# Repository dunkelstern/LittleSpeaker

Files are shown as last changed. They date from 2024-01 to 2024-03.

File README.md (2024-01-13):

---
title: LittleSpeaker
author: Johannes Schriewer
date: January 2024
toc: true
lof: true
numbersections: true
geometry: margin=2.5cm
urlcolor: blue
papersize: a4
header-includes: |
    \usepackage{fancyhdr}
    \pagestyle{fancy}
    \lfoot{13.01.2024}
    \rfoot{Page \thepage}
include-before:
- '`\newpage{}`{=latex}'
fontfamily: universalis
---

# LittleSpeaker

This is the Git-Repository for the LittleSpeaker Project. The idea is to build
a small mono speaker that is repairable, hackable and can do some more advanced things
than just being a Bluetooth speaker.

Design of the enclosure is by Jennifer Leis, Firmware and electronics by me.

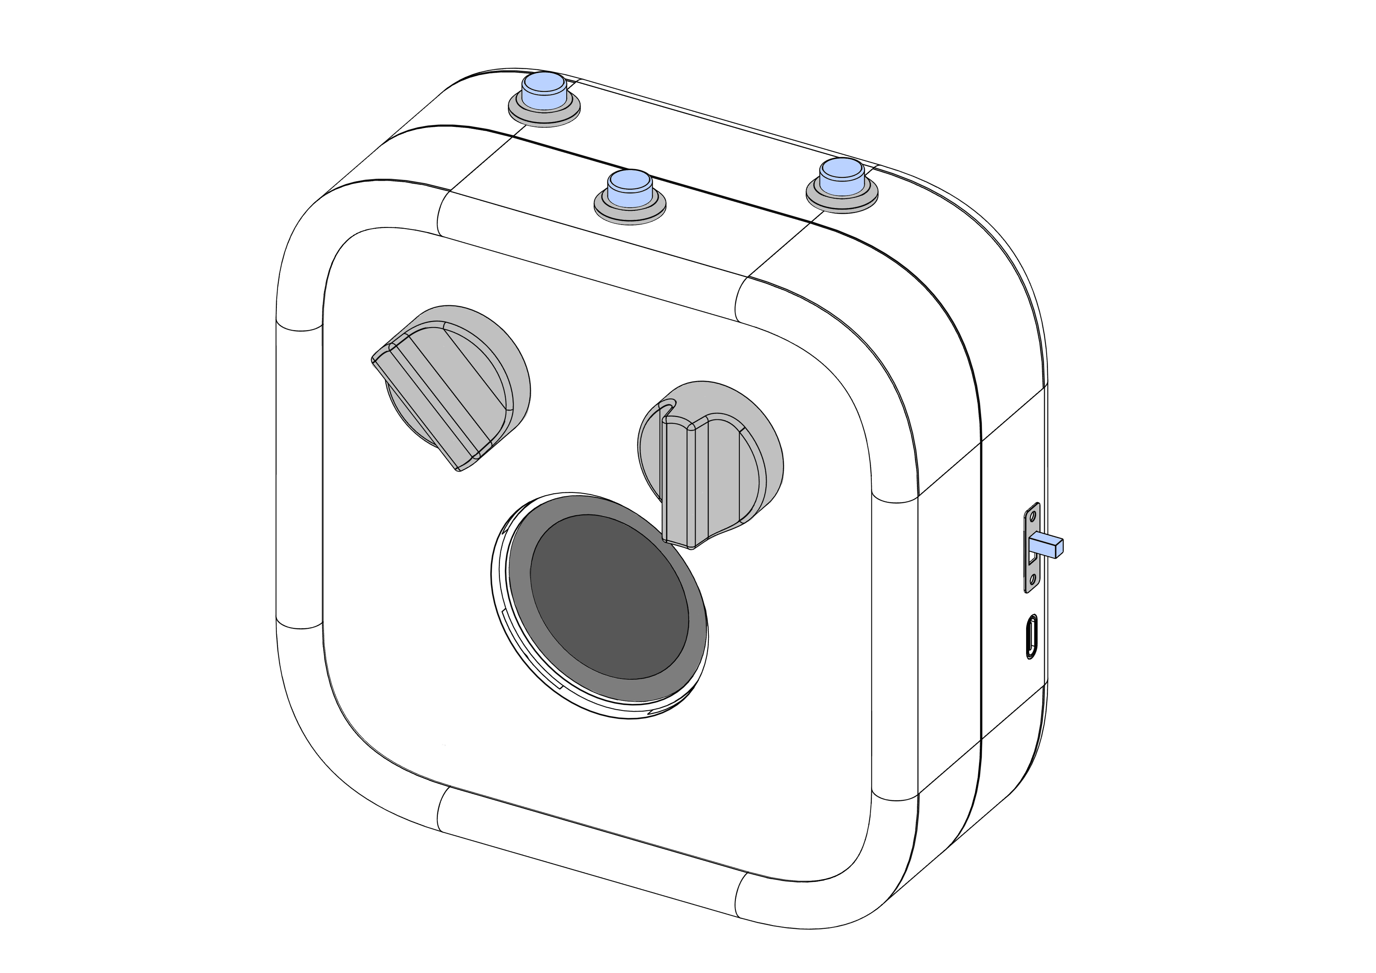
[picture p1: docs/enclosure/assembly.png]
Assembly graphic


\newpage{}

## Enclosure

The prototype enclosure was 3D printed and is held together by a hinge and just one
M3 screw.

You will need:

1. 1x [Front bezel](enclosure/front-bezel.step)<div>
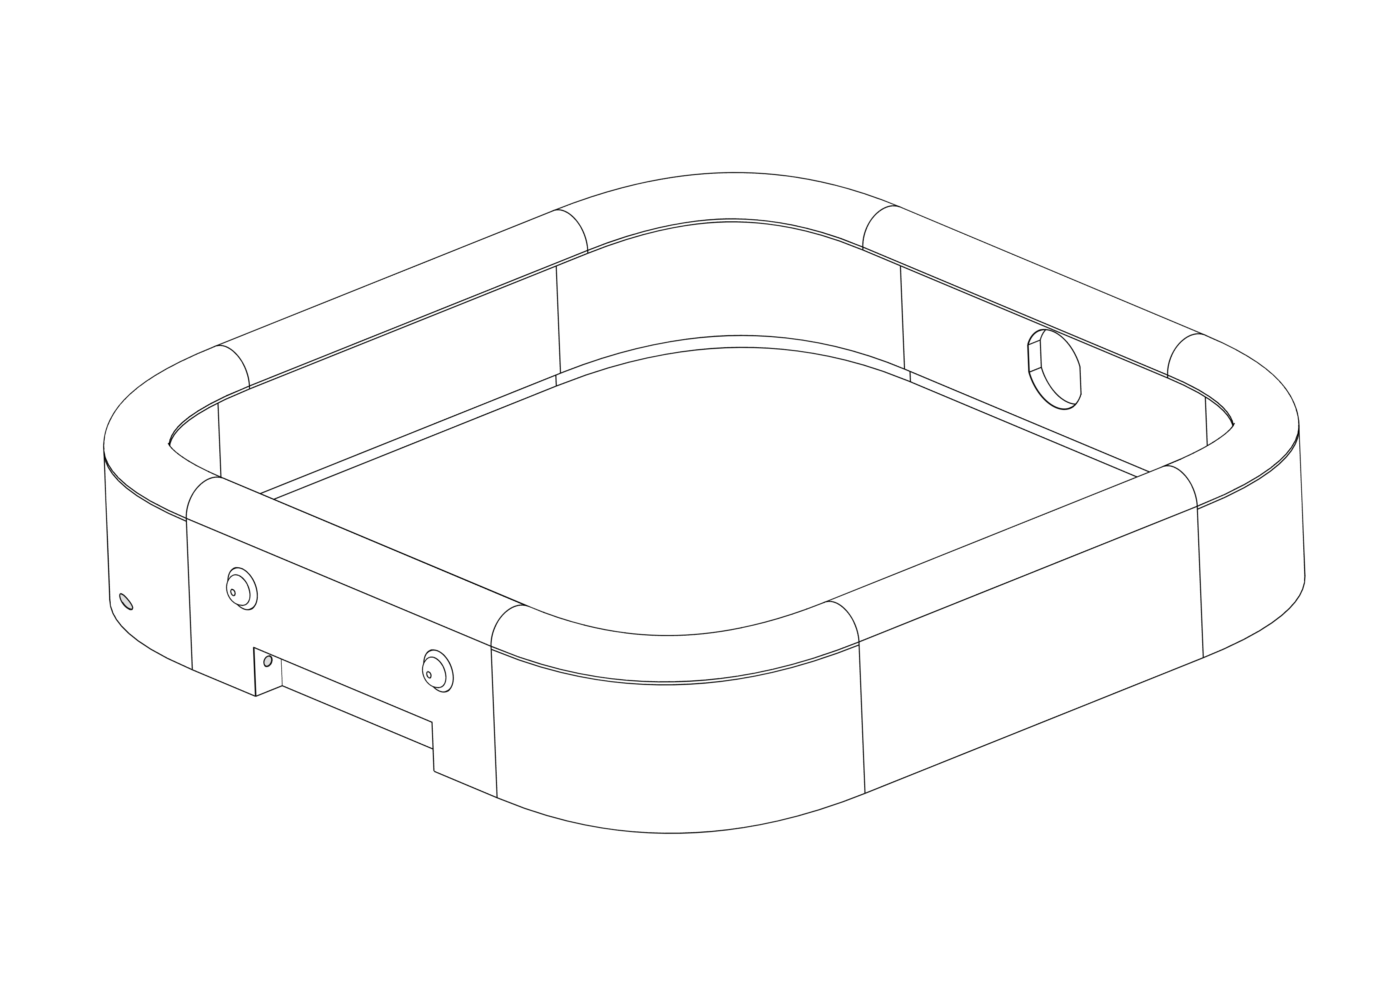
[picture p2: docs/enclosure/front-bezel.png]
Front bezel graphic
   </div>
2. 1x [Back bezel](enclosure/back-bezel.step)<div>
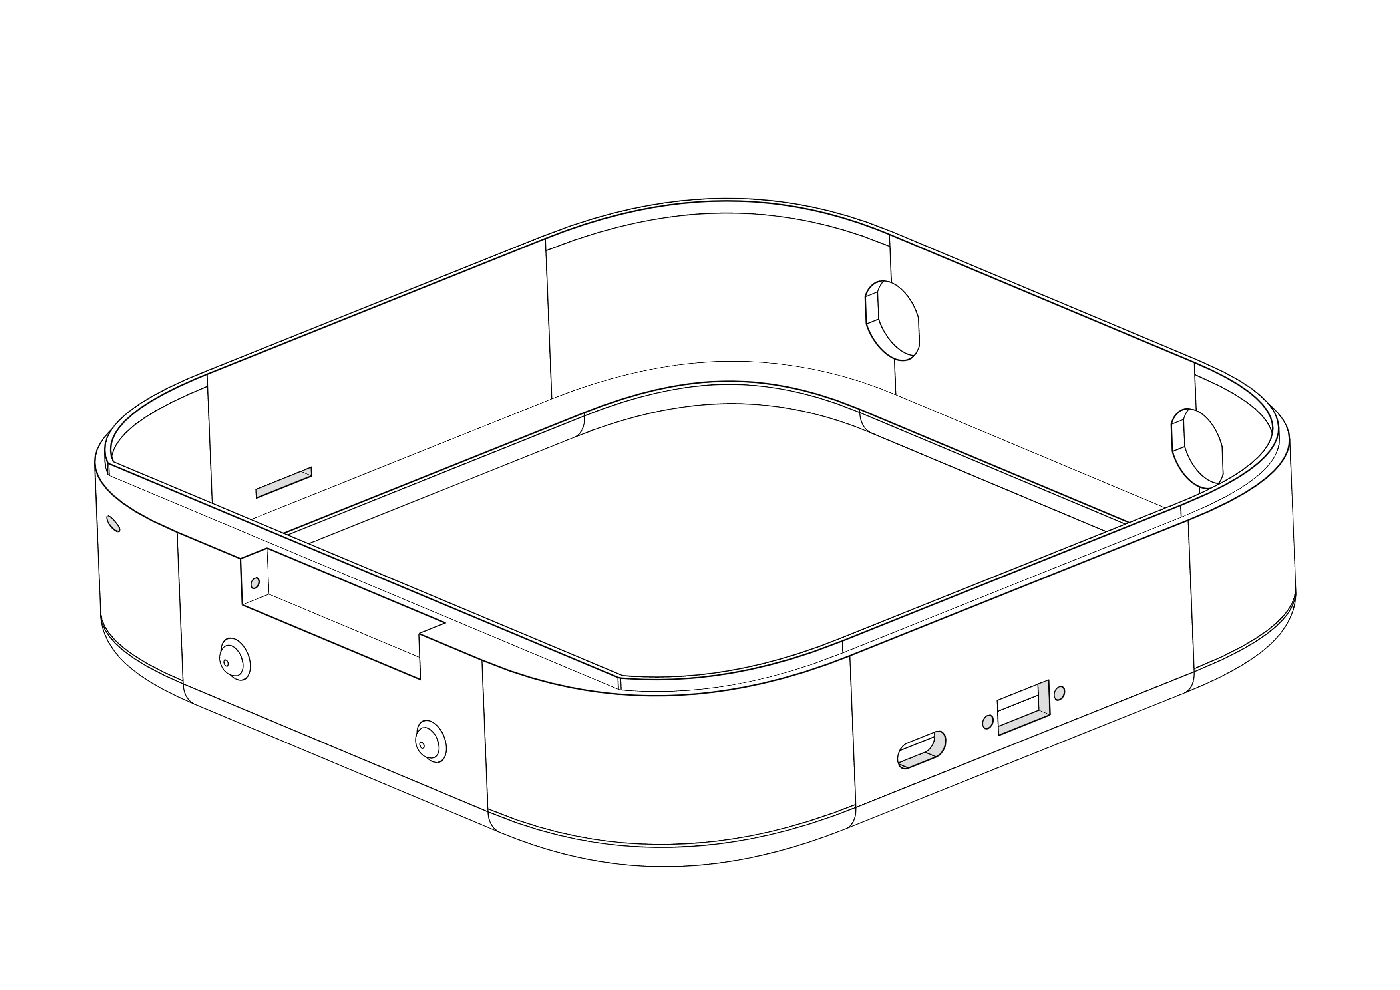
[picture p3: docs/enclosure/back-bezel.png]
Back bezel graphic
   </div>
3. 1x [Back plate](enclosure/back-plate.step)<div>
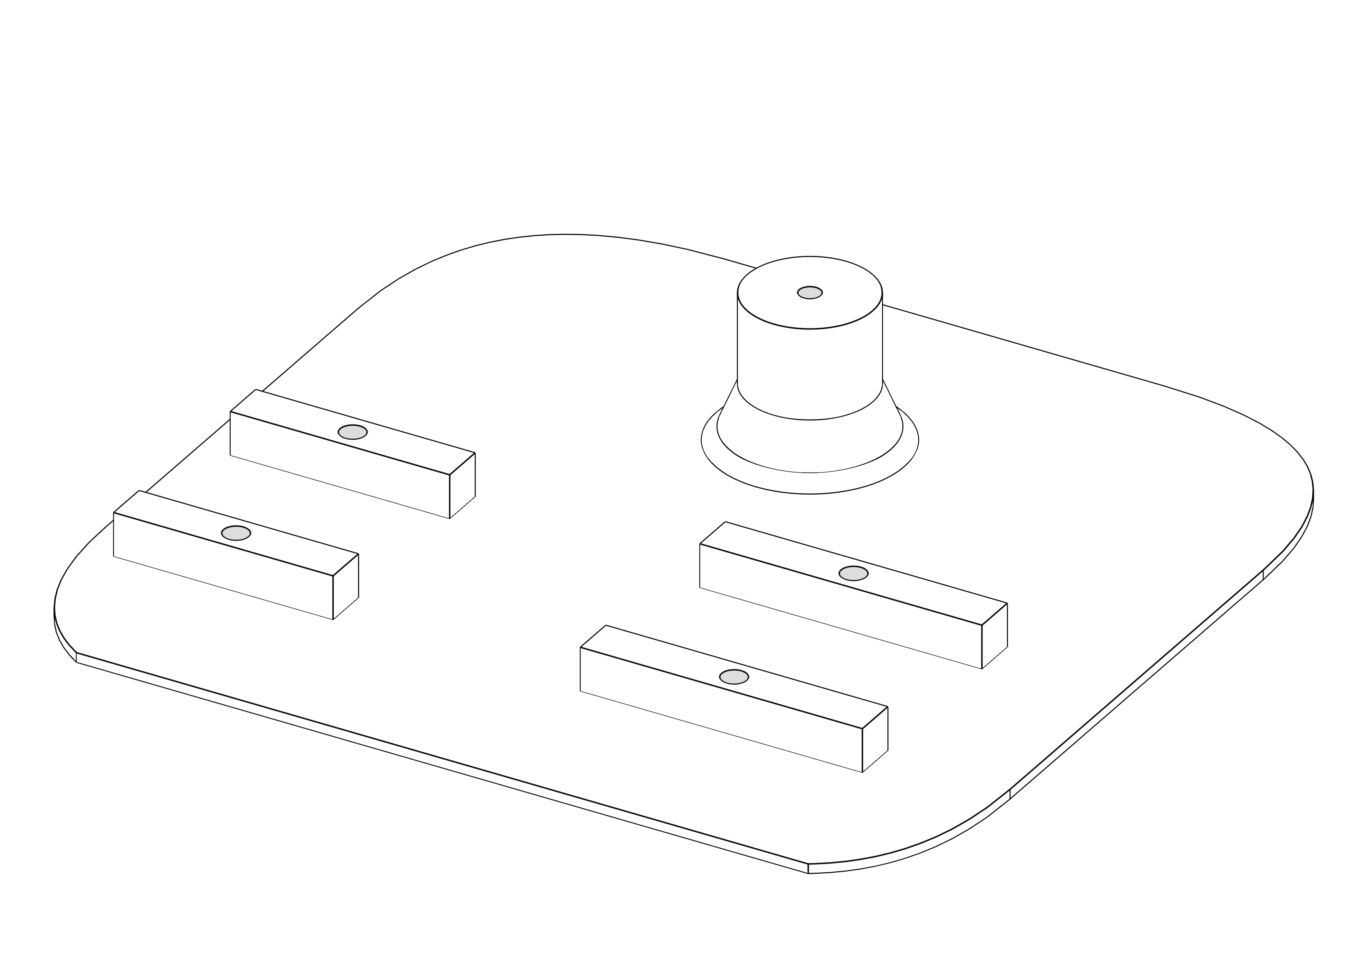
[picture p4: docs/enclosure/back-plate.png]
Back plate graphic
   </div>
4. 1x [Front plate](enclosure/front-plate.step)<div>
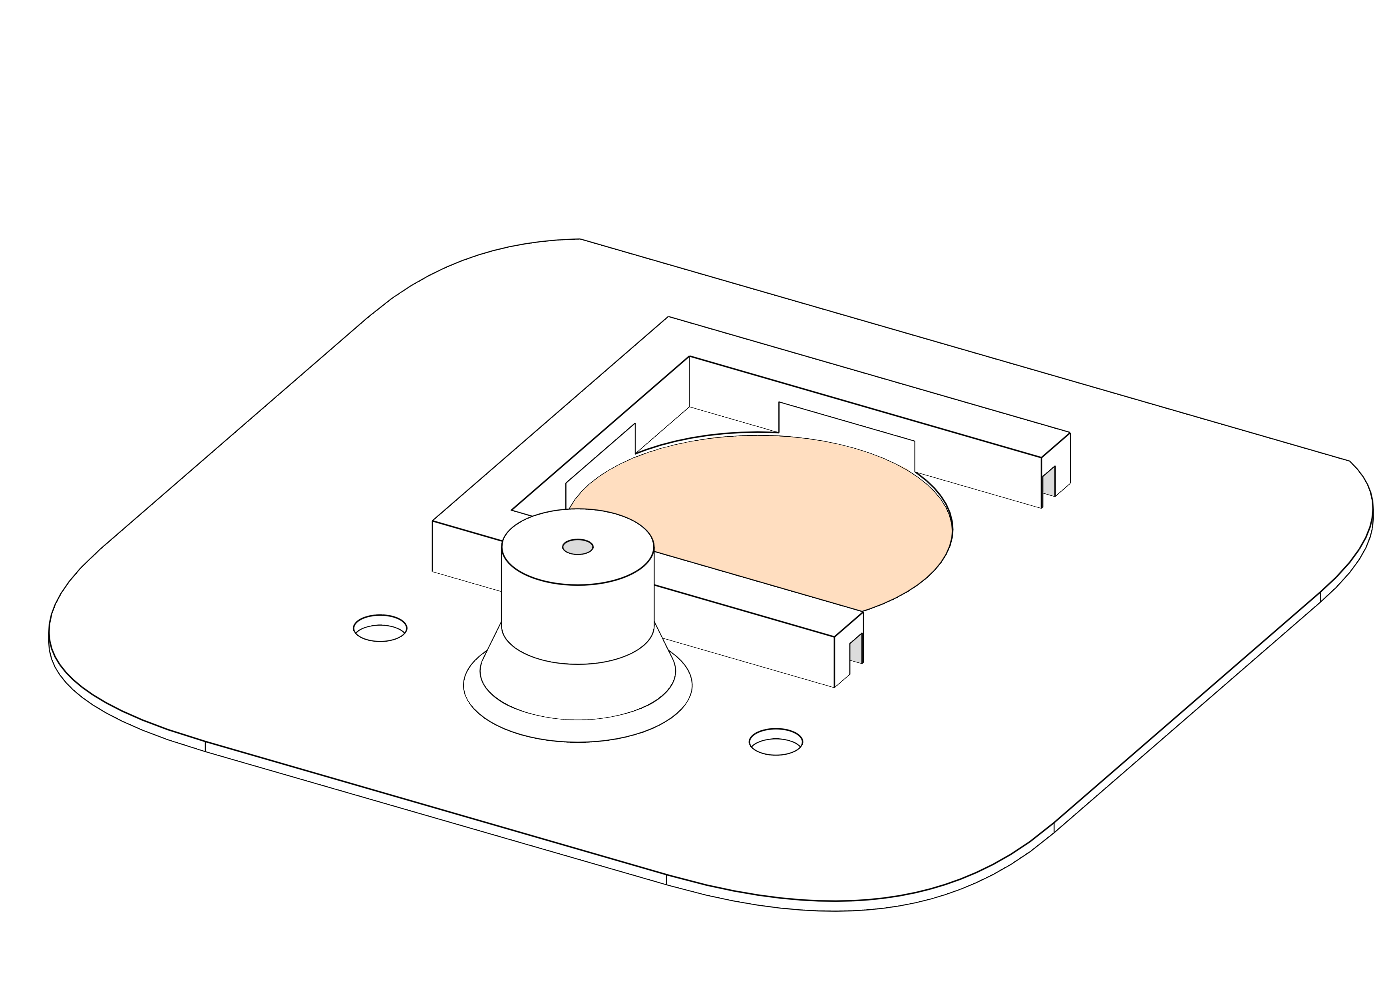
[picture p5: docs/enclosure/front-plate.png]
Front plate graphic
   </div>
5. 1x [Hinge](enclosure/hinge.step)<div>
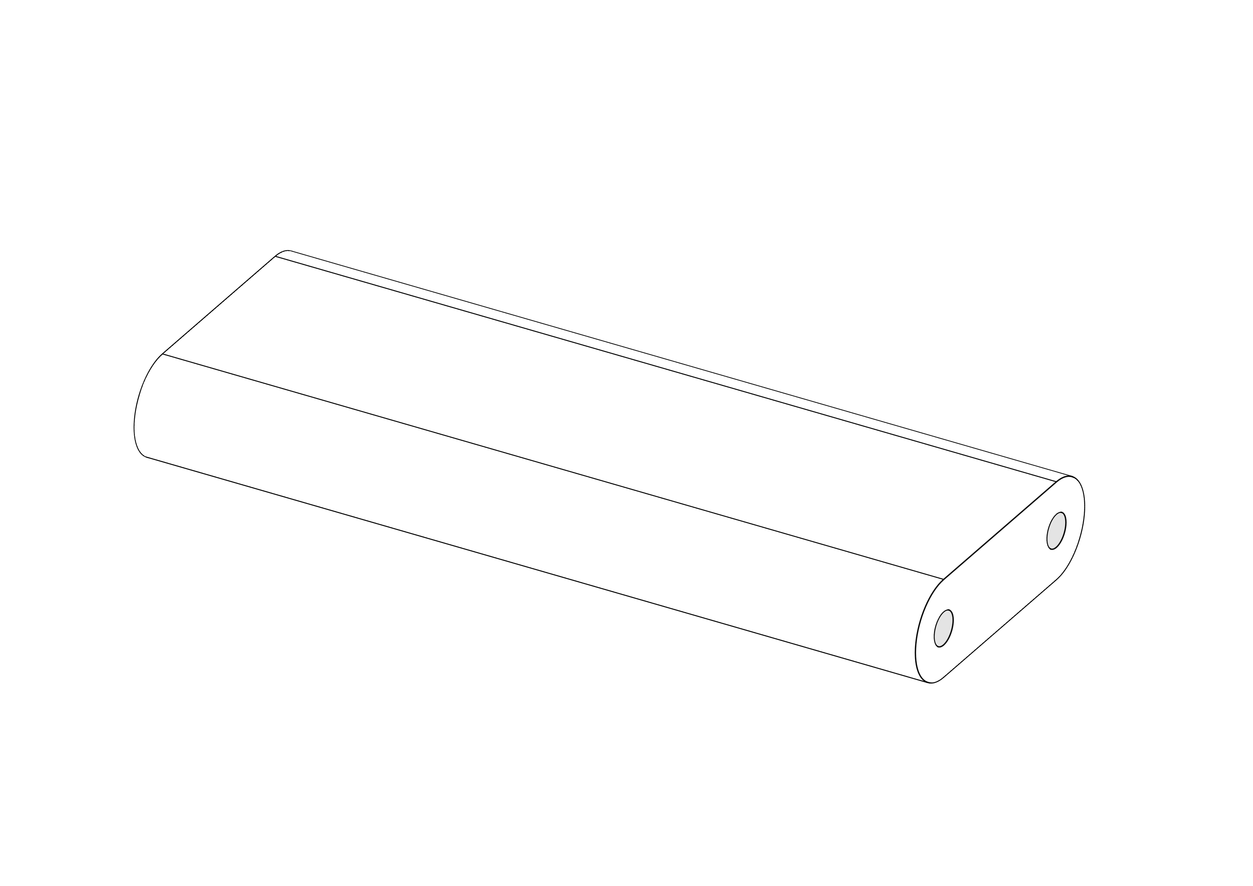
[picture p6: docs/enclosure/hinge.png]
Hinge graphic
   </div>
6. 2x [Knob](enclosure/knob.step)<div>
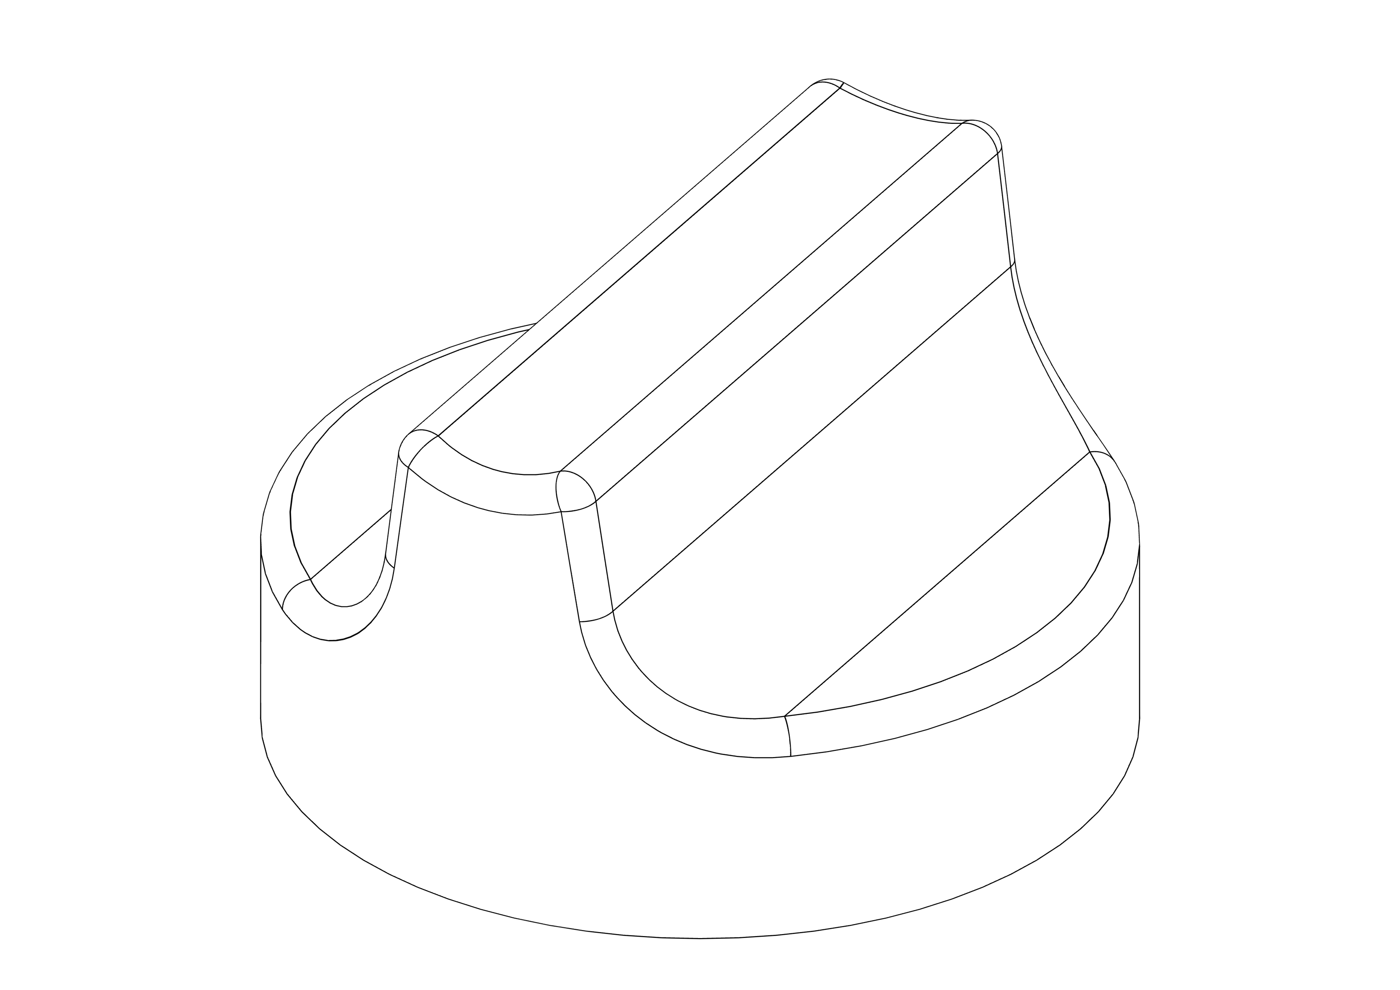
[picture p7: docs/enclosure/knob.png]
Knob graphic
   </div>
7. Two small pieces of wood or plastic as holding braces for the PCBs
   that will be accessible from the outside (15 x 40mm two M3 trough holes)<div>
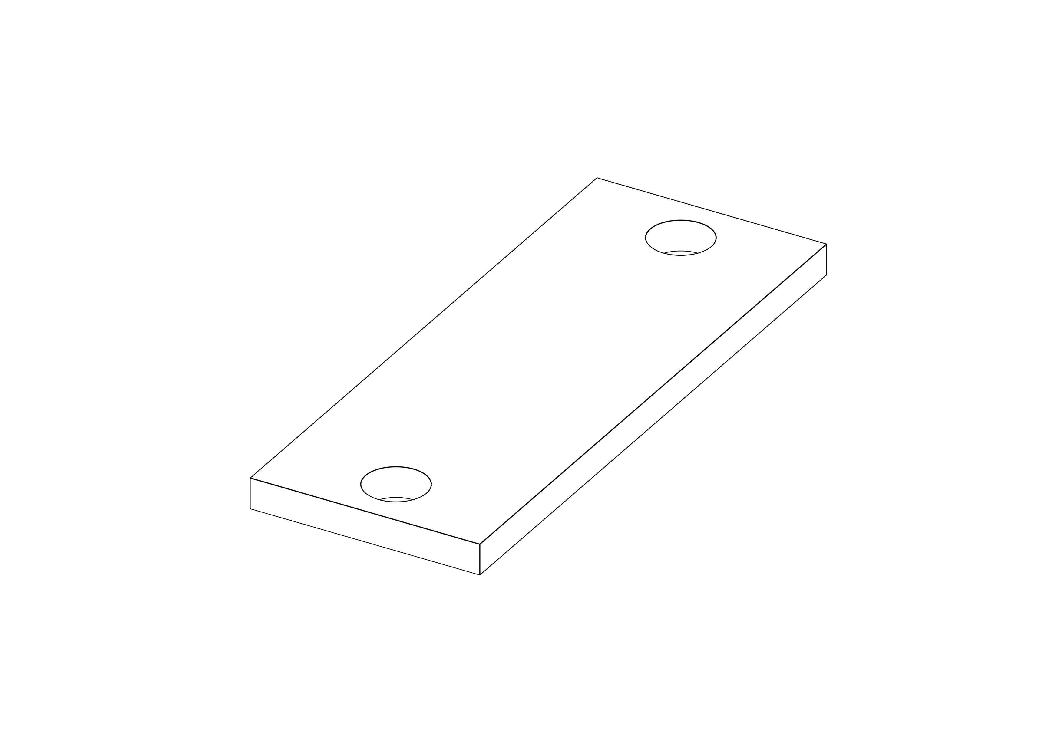
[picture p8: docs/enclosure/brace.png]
Braces graphic
   </div>
8. Brass hotmelt inserts for screwing the front and back together and for the braces:
   - 1 x M3x6
   - 4 x M3x4
   <div>
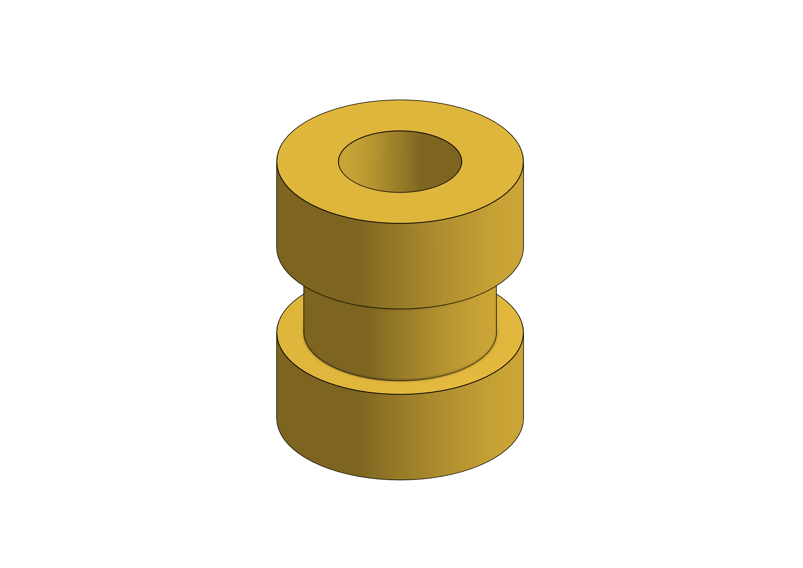
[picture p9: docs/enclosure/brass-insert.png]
Brass insert graphic
   </div>
9. 5x M3x10 Cap head screws
10. Some self-tapping screws to attach the power switch.
11. A piece of Copper wire to fit into the hinge to connect the front and back pieces
12. Glue to glue the front and back plates into the bezels and some foam rubber strips
    or foam tape for securing stuff
13. Some wool or cotton to fill the empty spaces so no wires rattle around.

When printing the front plate make sure to change the settings for the speaker grille
part to not print any bottom or top layers, use hexagon/honeycomb infill and use about 
40% infill strength. You can remove the speaker grille part if you want to have the
speaker open like you can see in the rendered graphic of the assembly.

\newpage{}

### After printing:

1. Remove the supports from the holding brackets of the speaker driver.
   There should be thin walled supports that have been designed into the part.
2. Melt the inserts into the brace holes and the front plate.
3. Glue the front and backplates into their bezels
4. Find a piece of copper wire that fits into the holes in the hinge.
   The front and back bezels both have a small hole through which you can insert
   the wire through the hinge part. If assembled and the hinge is freely rotating
   you can use a small screw driver to bend the wire in the hole to avoid it falling out.
   Alternatively insert a dab of glue to close the hole.
5. The SD card slot and USB-C port probably need some cleanup and filing to fit perfectly.

\newpage{}

## Electronics

The electronics in this devices are meant to be modular, so developer boards for all
components were used and the wiring connections mostly have dupont connectors to be able
to remove/replace a component without de-soldering anything. You can of course skip the
connectors and solder everything together, that's your choice.

### BOM

- DFRobot Firebeetle 2 ESP32-E (ESP32 development board with battery charger and USB-C)<div>
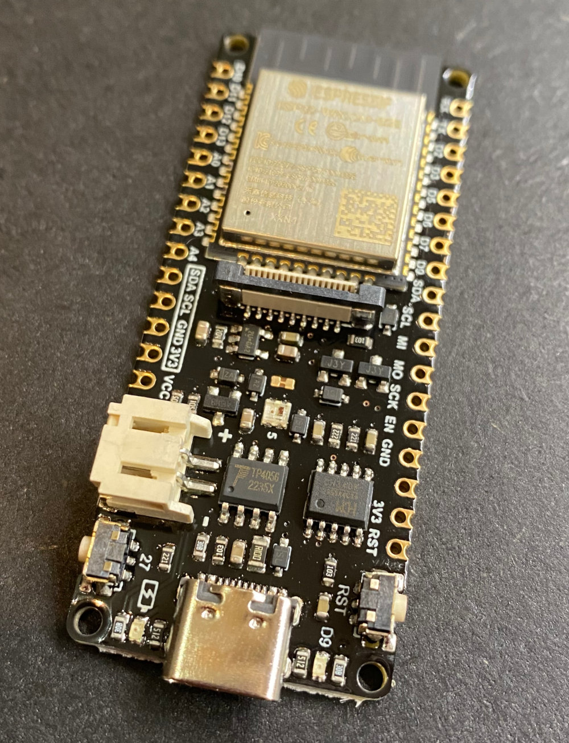
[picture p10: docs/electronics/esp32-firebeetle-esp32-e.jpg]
Firebeetle ESP32-E
  </div>
- I2S DAC usually something like a `PCM5102A`<div>
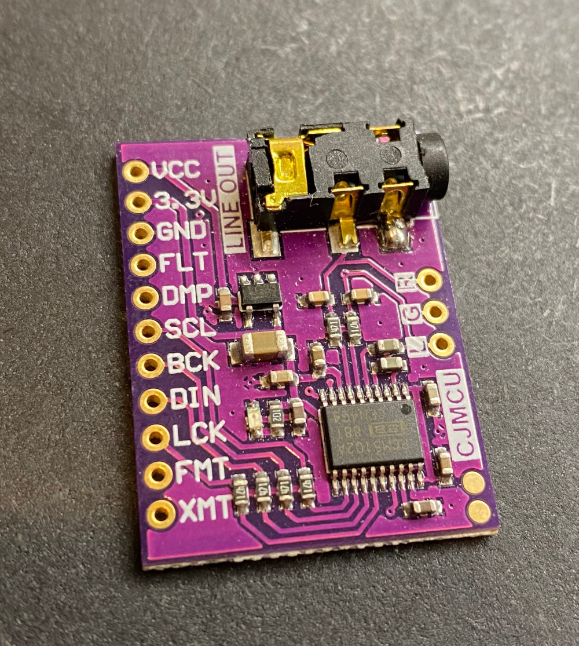
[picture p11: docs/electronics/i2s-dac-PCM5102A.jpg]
I2S DAC
  </div>
- Micro SD Card reader, see below for more instructions!<div>
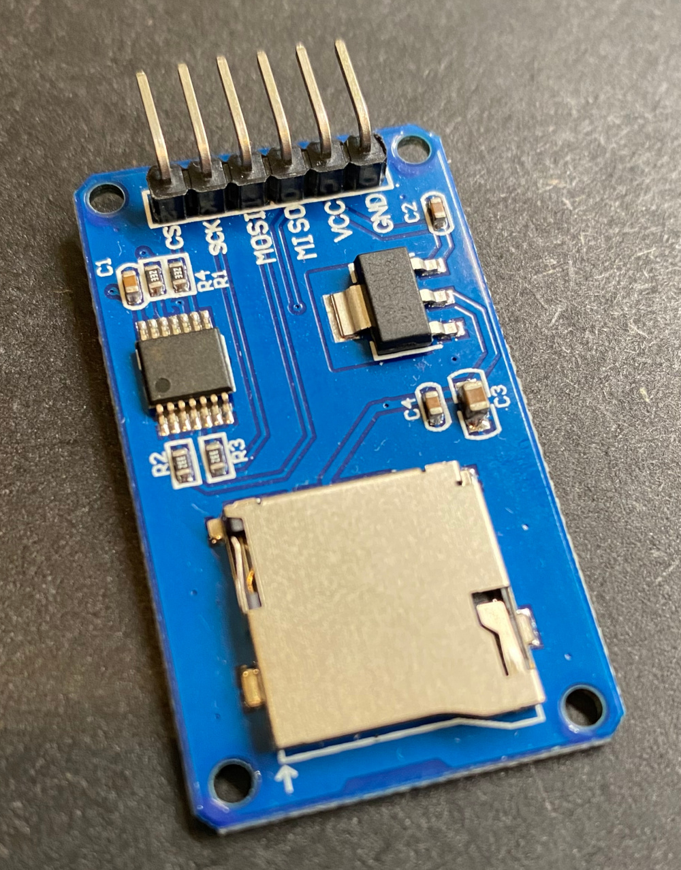
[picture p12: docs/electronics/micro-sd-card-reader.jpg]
SD-Card Reader
  </div>
- Class D Amplifier for 1.5W to 4W with volume regulation, for example `PAM8403`<div>
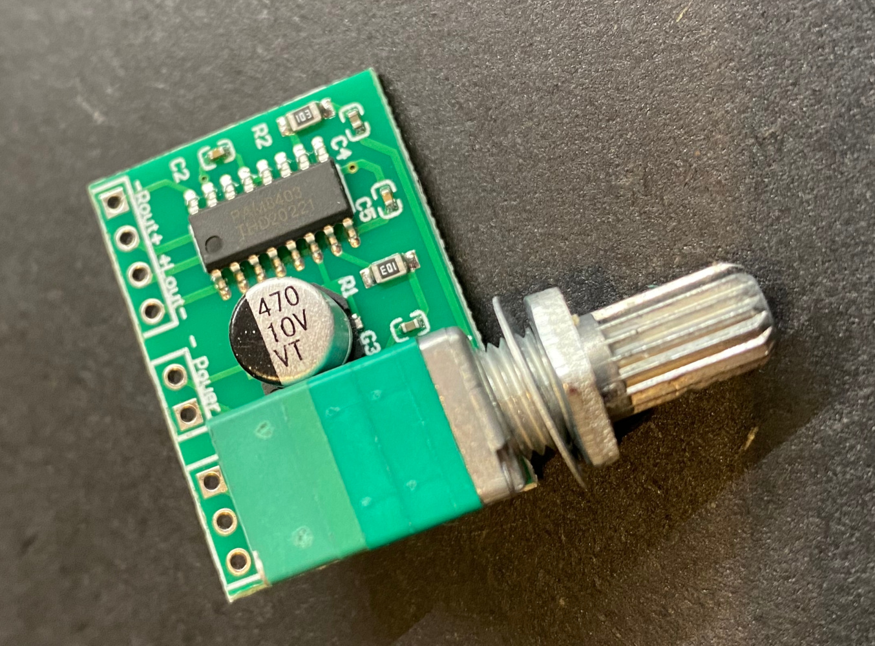
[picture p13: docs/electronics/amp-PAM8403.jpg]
Class D amp
  </div>
- "57mm Speaker" (yes this is the search term). You can probably use any speaker you
  want as long as it is 4-8 Ohms and can work with your amplifier.<div>
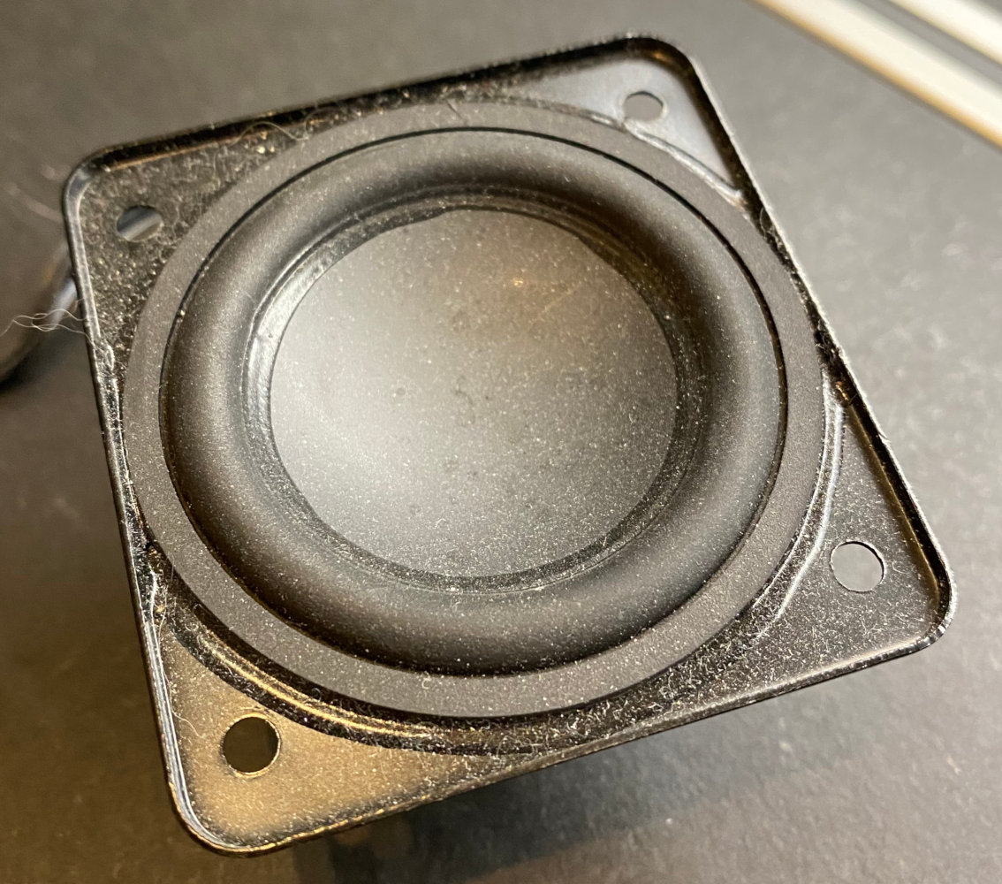
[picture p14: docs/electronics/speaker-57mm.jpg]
Speaker
  </div>
- LiIon 18650 Battery<div>
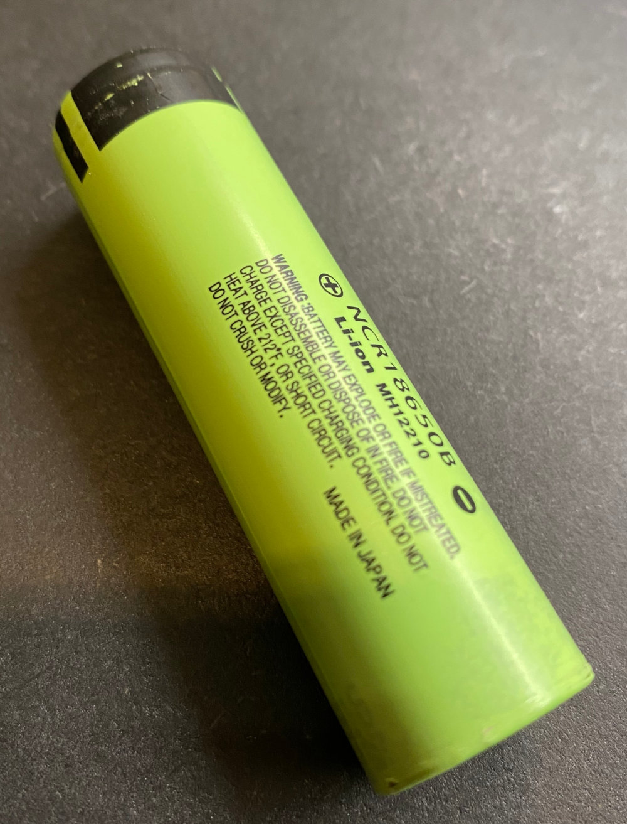
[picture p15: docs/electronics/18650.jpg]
  </div>
- Battery holder<div>
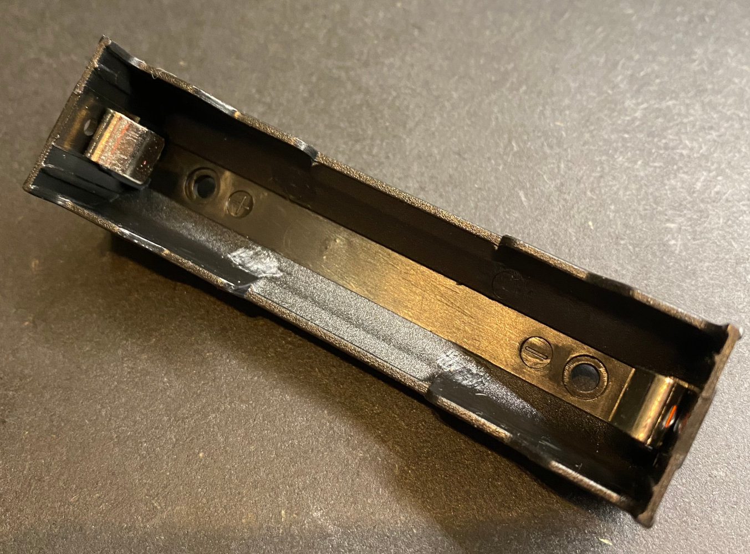
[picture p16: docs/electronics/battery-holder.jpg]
Battery holder
  </div>
- 3x Round pushbutton. If you cannot find these, you probably can use others if you
  have some patience and a file for the holes ;)<div>
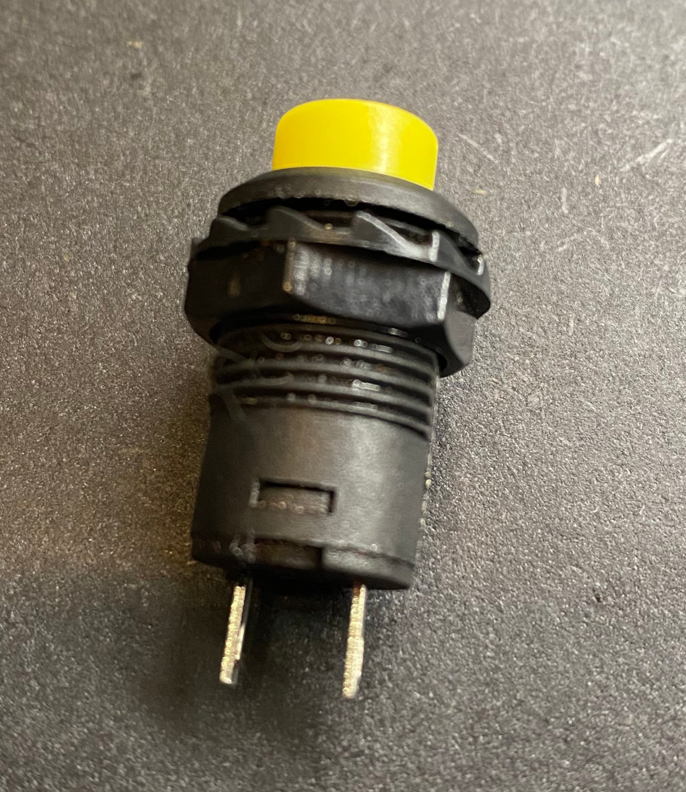
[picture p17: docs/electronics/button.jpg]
Buttons
  </div>
- Sliding switch for power<div>
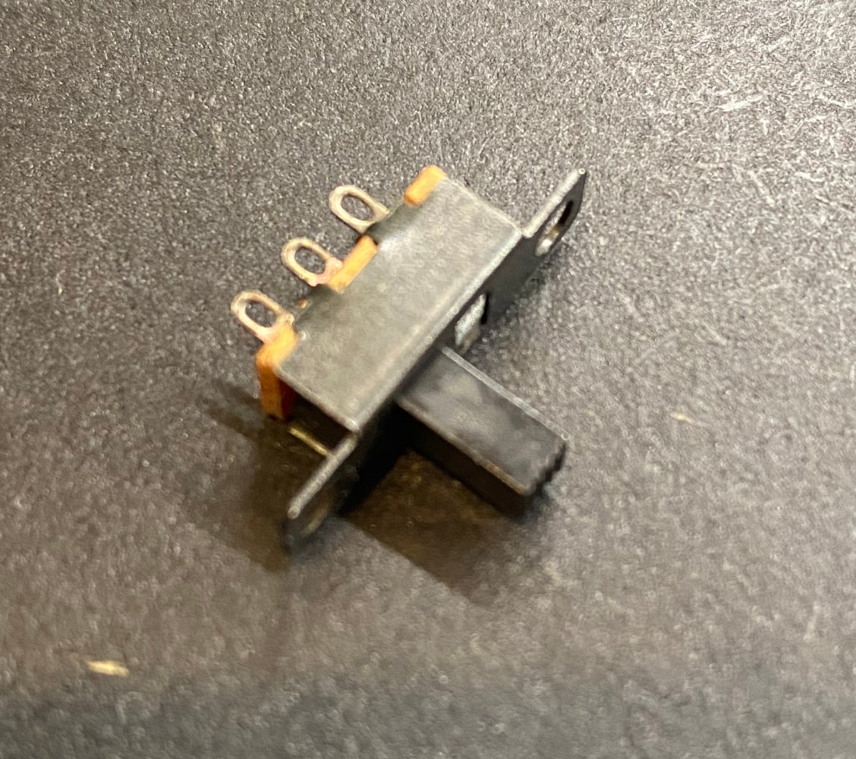
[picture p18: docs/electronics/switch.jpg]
Switch
  </div>
- Encoder with pullups, you can get modules that have pullups integrated, if you
  have no pullups integrated you can integrate resistors in your wiring.
  *Attention: this is not a potientometer but a gray encoder!*<div>
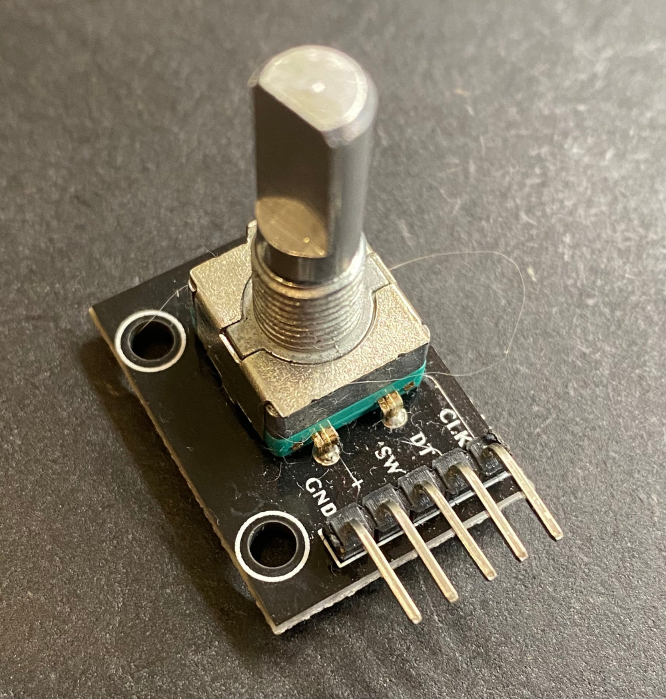
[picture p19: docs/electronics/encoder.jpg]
Encoder
  </div>
- 3 x 1kOhm resistor as pull up for the buttons
- Some multi colored wires, a soldering Iron and patience

\newpage{}

**SD-Card reader:**

Get a reader that has the Card slot as close to the edge as possible, if it is not at the
edge you can usually file away some of the FR4 board to make it fit. (Usually there are no traces there to destroy...).

<div>
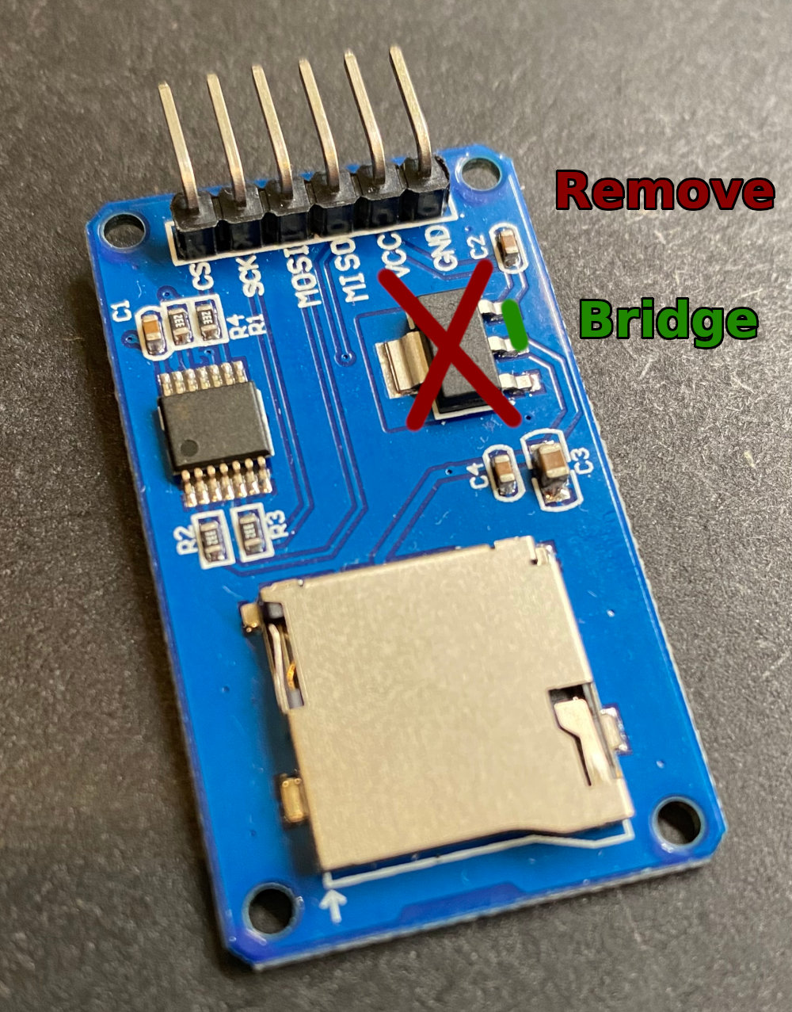
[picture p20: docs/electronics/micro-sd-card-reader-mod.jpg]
SD-Card reader Mod

</div>

Most SD-Card readers you can get on the market are designed to be used with 5V electronics
and contain a linear regulator (red X) to step down that voltage to 3.3V. As the ESP32
works on 3.3V already you'll have to remove that LDO because the minimal voltage it needs
to run is usually 4.5V. When removing the part either use hot air or just a soldering
iron and cook  that thing, as we won't be needing it you do not have to save it. After
removal just bridge input and output of the part (marked in green).

\newpage{}

### Wiring

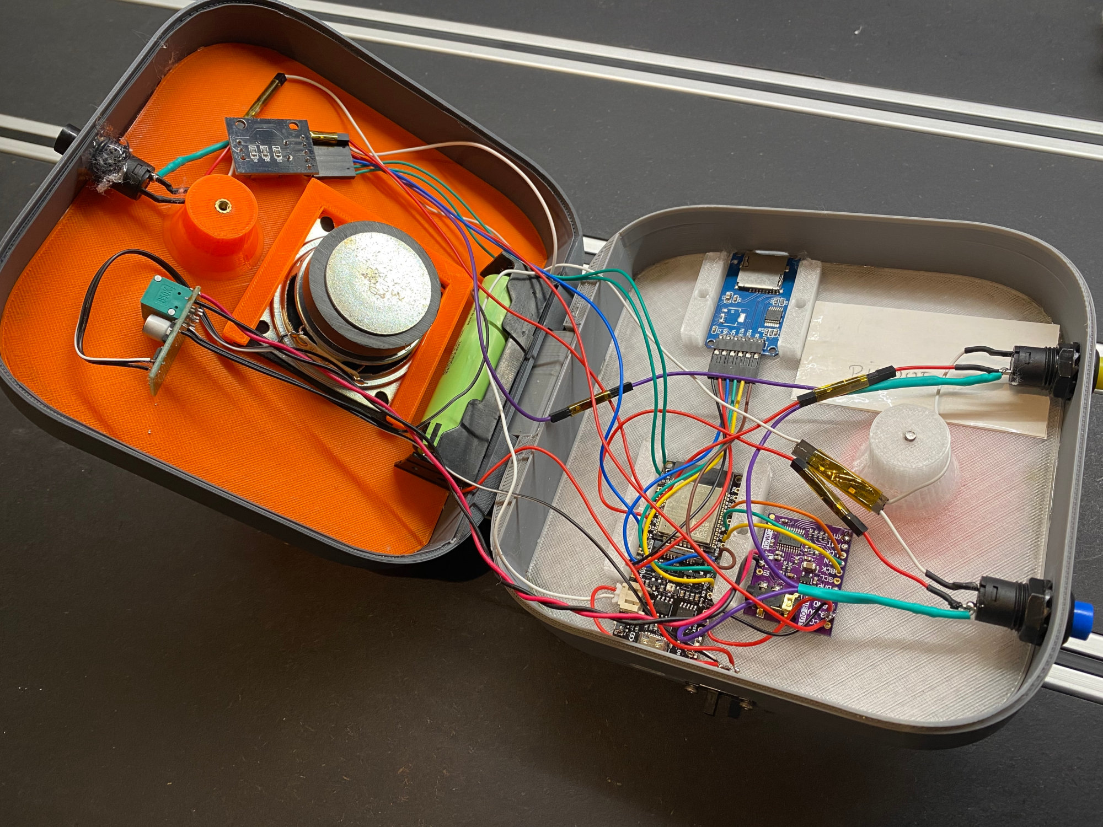
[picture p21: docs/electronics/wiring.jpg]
Wired up


Open the [Schematic](electronics/schematic/outputs/schematic.pdf) from `electronics/schematic/outputs/schematic.pdf`

<div>
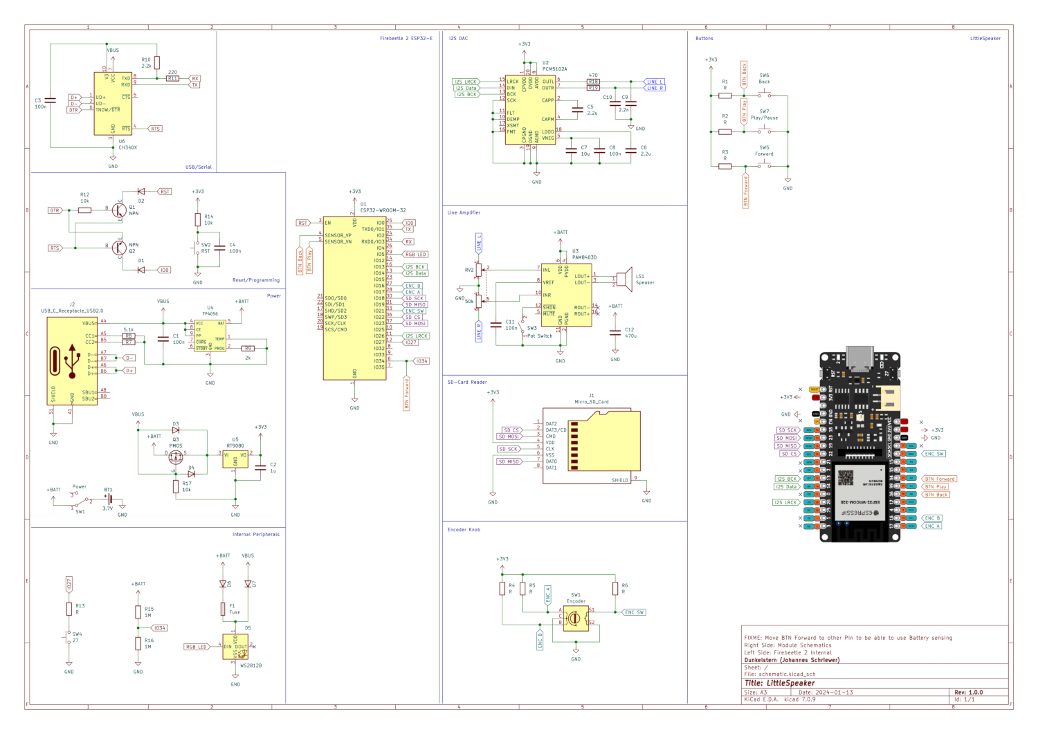
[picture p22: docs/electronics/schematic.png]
Schematic preview

</div>

Make sure to connect the Amplifier directly to the battery and **not** the ESP32. You will crash the ESP with loud music as the regulator on the PCB will not deliver enough power!

For the button pullup resistors I soldered them in-line with a wire and applied heatshrink over them (greenish heatshrink in the photo).

The development boards are glued with double sided tape and if needed you can apply the braces on top and stuff them with some foam tape or something rubbery to hold the boards down firmly.

The Speaker will slide into the printed rails but it will rattle around, you need some
foam tape or foam rubber strips to wedge the speaker into.

\newpage{}

## Firmware

The firmware is in this repository and is to be built with platform.io

The Arduino framework is used and these external libraries:

- ESP8266Audio 1.9.7 (Audio components)
- RotaryEncoder 1.5.3 (Encoder knob)
- AceButton 1.10.1 (Buttons)
- FixedPoints 1.1.2 (3 Band Equalizer)

Just open this repository in a Platform.io IDE of your choice and click "Build and Upload"

### Stuff you may want to change

**SD-Card read speed**

If you get errors on the serial debug console output about the SD-Card not working, you may have a slow SD-Card, go to `src/main.cpp` around line 35 and change the following line:

```cpp
#define SPI_SPEED 4000000u
```

40 MHz is the default and the maximum speed the ESP32 can handle. Try reducing to 20MHz
or 15 MHz until the SD-Card works. If you go too slow sound will be crackling and boot
times will increase.

**Equalizer settings**

As the EQ settings depend on the materials you printed the enclosure, print settings and
the used speaker driver you probably want to play with those settings a bit. You can find
them in `src/main.cpp` at around line 150.

Search for these lines:

```cpp
  eq = new AudioOutputFilter3BandEQ(output, 500, 5000);
  eq->setBandGains(1.5, 0.9, 1.3);
```

The first line sets the cutoff frequency of the EQ bands, so in this example we have 3
Bands:

- 0-500 Hz
- 500-5000 Hz
- 5000-22050 Hz

Those values are approximate as the algorithm implemented for the EQ is very simple and
not accurate at all, but as we're dealing with very simple and cheap components here it is
usually ok to use that.

The second line sets the equalizer band gains. If you set them all to *1.0* you should 
hear the original sound. I recommend to use values in the range of *0.75* to *1.5*. If you
go under or over those the sound may distort or clip, I warned you!

## SD-Card

To properly function the speaker needs an SD-Card to store voice prompts and 
configuration. I personally tried with 16GB SD-Cards and it worked fine (those were the
smallest cards i could get from my supplier), I think that is enough space for this project as two full days of music are just under 4GB and if you put too many directories
on there the boot time of the device will take ages as it needs to build an index of the
contents on boot up.

To prepare the SD-Card for the speaker:

1. Format the SD-Card to FAT32
2. Put all files from the `sd-card` folder directly onto the SD-Card
3. Read the [Readme](sd-card/README.md) of the SD-Card for more information

\newpage{}

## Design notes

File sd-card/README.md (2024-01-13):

# SD-Card contents

This is a quick how-to for the SD-Card contents of LittleSpeaker

## root files

We have some files that reside on the root directory (Top level, under
windows this is directly on the drive in no folder).

- `wifi.txt` WiFi settings, this file contains 2 lines:
   1. WiFi name, attention this is case sensitive
   2. WiFi password in plaintext
- `webradio.txt` URLs to webradio streams, start a line with `#` to
  include comments. See *webradio* below for more info

If the connection to the WiFi does not work check the following:

1. WiFi has to be on the 2.4GHz band, 5GHz does not work
2. WiFi has to support WPA2
3. If nothing else is the problem, check that you're using "Unix line endings",
   this is usually only a problem on Windows machines.

## System directory

The `system` directory should contain the announcer voice files to be used for
the menu system, I will describe which one is which in the following.

The default announcer voice has been generated with a text to speech computer
voice, but if you want you can exchange them for another voice.

Format of the files should be a *stereo* MP3 file with a reasonable bitrate and
length usable for the task. Remove all ID3 tag data to make the menu more
responsive.

- Numbers 1 to 99 (e.g. `1.mp3`): Will be used for
  - Album numbers if there is no announcer (see below at *album directories*)
  - Track numbers in albums
  - Webradio station numbers
- `album.mp3` used before an album number
- `bluetooth_on.mp3` used when entering the bluetooth menu and turning bluetooth on
- `bluetooth_pair.mp3` played when a device pairs to LittleSpeaker in bluetooth mode
- `bluetooth.mp3` menu title for the bluetooth menu
- `connection_failed.mp3` played when a connection to a webradio station fails or is
  disconnected by the server.
- `hello.mp3` will be played on bootup after SD-Card index has been created
- `sd.mp3` menu title of the SD-Card menu
- `stopped.mp3` played when an album has finished, the user disconnects a webradio
  station by pressing stop or when a device disconnects from bluetooth
- `track.mp3` played when in an album before the track number
- `webradio.mp3` menu title of webradio menu

## webradio

### Requirements

There are some things you'll have to consider for the streams that can
be played by the firmware of LittleSpeaker:

1. The stream has to be an IceCast or ShoutCast stream.
2. You have to link to a stream, not the stream's playlist. Usually webradio
   stations will link a playlist file (either `m3u`, `m3u8` or `pls`) which
   contains multiple streaming URLs to provide multiple servers.
3. The stream has to be MP3, AAC and HeAAC (or AAC+) do not work currently.
4. Keep the bitrate at a reasonable value, 320 kBit is cool and all, but you
   will probably not hear a difference to a 192 kBit (or even a 128 kBit) stream.
5. Try to keep to http and not https as it is faster to process on device
6. Maximum line/URL length is 255 characters
7. Maximum number of stations is 25

### Announcer

If you want LittleSpeaker to tell you a webradio name instead of the channel
number in the menu you can add an audio file to the `webradio` directory. The
file should be a *stereo* MP3 file with a reasonable bitrate and length.
Name it the channel number in two digits (leading zero). The file will be played
back if you select the channel.

### Verification

To verify a Stream URL fetch it with curl like this:
```
curl -v http://ice2.somafm.com/groovesalad-128-mp3
```

   You will get an output like this:
```
*   Trying 173.239.76.149:80...
* Connected to ice2.somafm.com (173.239.76.149) port 80
> GET /groovesalad-128-mp3 HTTP/1.1
> Host: ice2.somafm.com
> User-Agent: curl/8.4.0
> Accept: */*
> 
< HTTP/1.1 200 OK
< Content-Type: audio/mpeg
< Date: Fri, 12 Jan 2024 18:42:54 GMT
< icy-br:128
< icy-genre:Ambient Chill
< icy-name:Groove Salad: a nicely chilled plate of ambient beats and grooves. [SomaFM]
< icy-notice1:<BR>This stream requires <a href="http://www.winamp.com/">Winamp</a><BR>
< icy-notice2:SHOUTcast Distributed Network Audio Server/Linux v1.9.5<BR>
< icy-pub:0
< icy-url:http://somafm.com
< Server: Icecast 2.4.0-kh15
< Cache-Control: no-cache, no-store
< Expires: Mon, 26 Jul 1997 05:00:00 GMT
< Connection: Close
< Access-Control-Allow-Origin: *
< Access-Control-Allow-Headers: Origin, Accept, X-Requested-With, Content-Type, Icy-MetaData
< Access-Control-Allow-Methods: GET, OPTIONS, SOURCE, PUT, HEAD, STATS
< 
Warning: Binary output can mess up your terminal. Use "--output -" to tell 
Warning: curl to output it to your terminal anyway, or consider "--output 
Warning: <FILE>" to save to a file.
* Failure writing output to destination
* Closing connection
```

It is good if curl tells you the content is a binary stream as this means
you actually got a stream URL and not the playlist that is linked. If you get
back text, it's probably a list of URLs. Sometimes you will get back a redirect
which means the service jumps to another server, you will see that if a `Location`
header is in the server response. Try that URL instead.

To verify you got an IceCast stream look for `icy-`-Headers which tell the device
Stream metadata.

You will get back a `Content-Type`-Header usually. This should be `audio/mpeg` for
streams that are supported. If you get `audio/aac` or something like that you
got an incompatible stream.

## Album directories

All directories that are not named `system` or `webradio` are assumed to be
music albums that can be played back. The Firmware can currently only play back
MP3 files, but some MP3 files contain big chunks of ID3 Metatag data and will
crash the Firmware. So if you're selecting an album, press play and then hear
the announcer voice greeting you with a *hello* something went wrong. Check
if you can remove the metadata from the files to fix that. Also make sure to
put *stereo* MP3 files on the SD-Card, mono files may play back at double speed.

If you want LittleSpeaker to announce your albums put a `album.mp3` in each
directory that should have a title. If that file is missing you will get an
announcer that tells you something like `Album thirtyfive` when selecting the
album on the menu.

If for some reason the album will play back in a wrong order you can put an
`album.m3u` or `album.m3u8` into the directory. The firmware will then use the
order specified in that playlist. Make sure the playlist only lists the filenames
without any directory traversal.

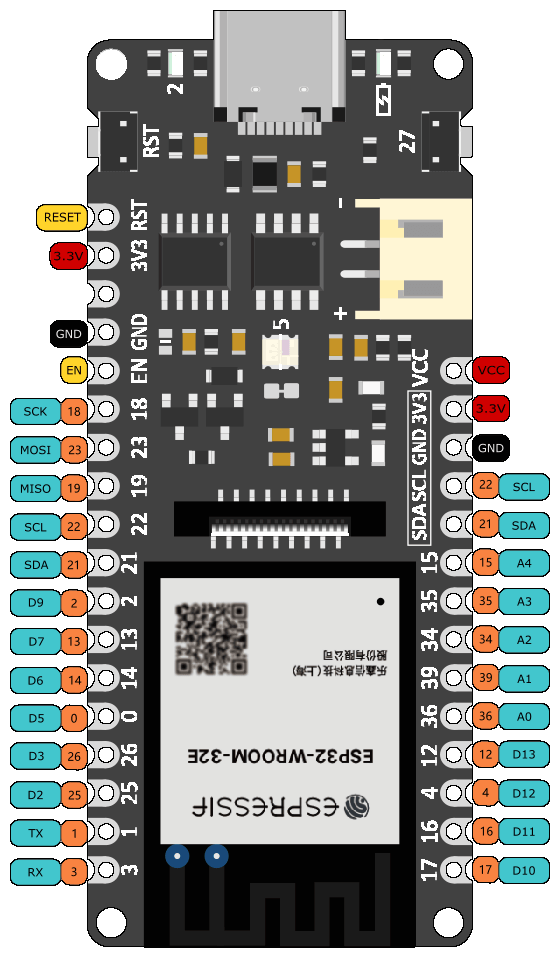
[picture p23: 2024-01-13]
docs/electronics/firebeetle_transparent.png

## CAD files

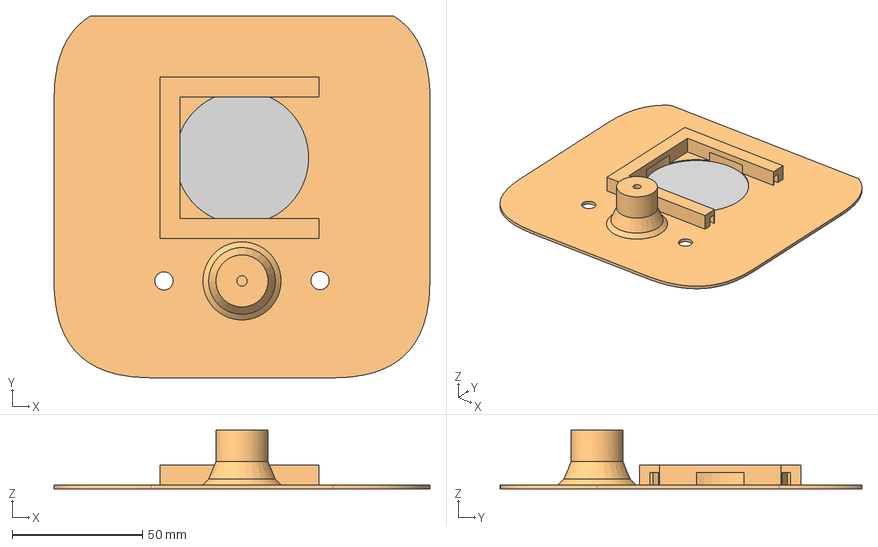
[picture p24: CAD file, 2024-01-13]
enclosure/frontplate.step
144.5 x 139.0 x 22.5 mm

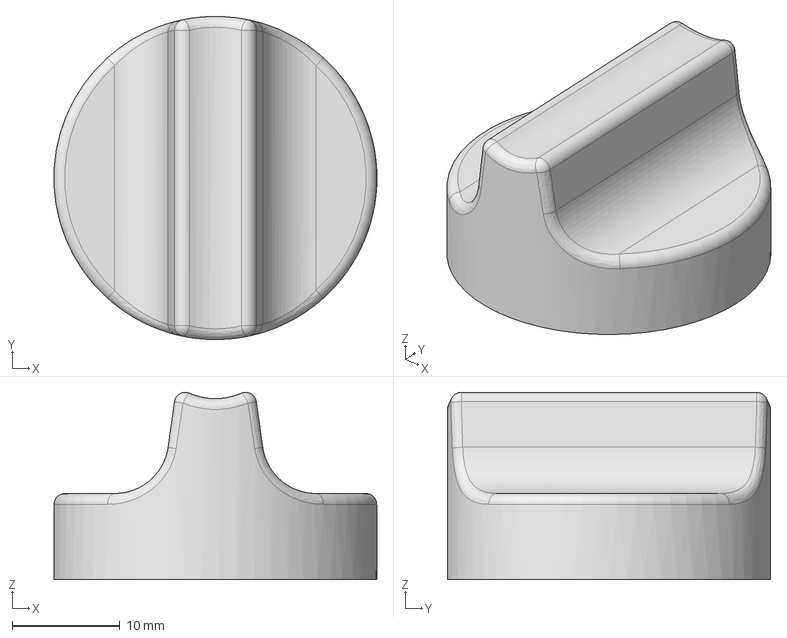
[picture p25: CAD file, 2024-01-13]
enclosure/knob.step
30.0 x 30.0 x 17.4 mm

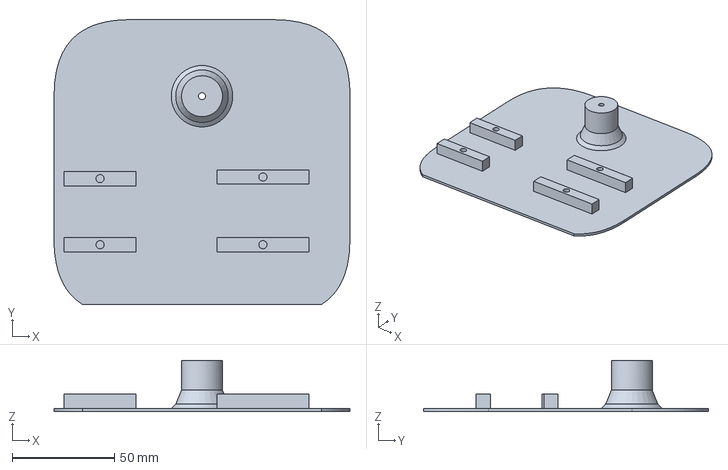
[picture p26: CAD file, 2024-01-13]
enclosure/backplate.step
144.5 x 139.0 x 25.0 mm

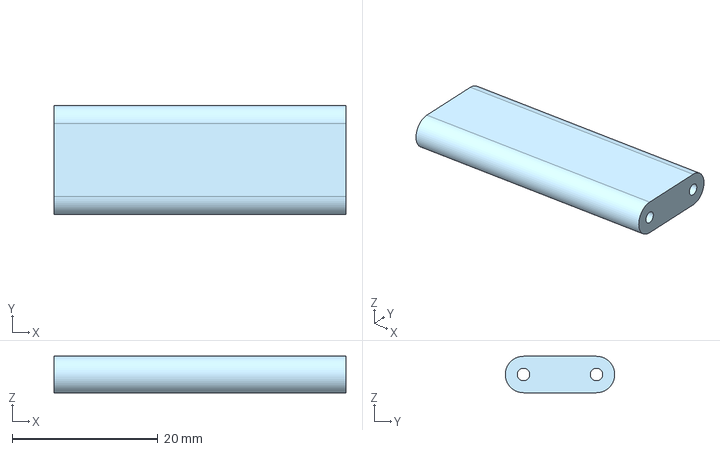
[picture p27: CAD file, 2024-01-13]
enclosure/hinge.step
40.0 x 15.0 x 5.00 mm

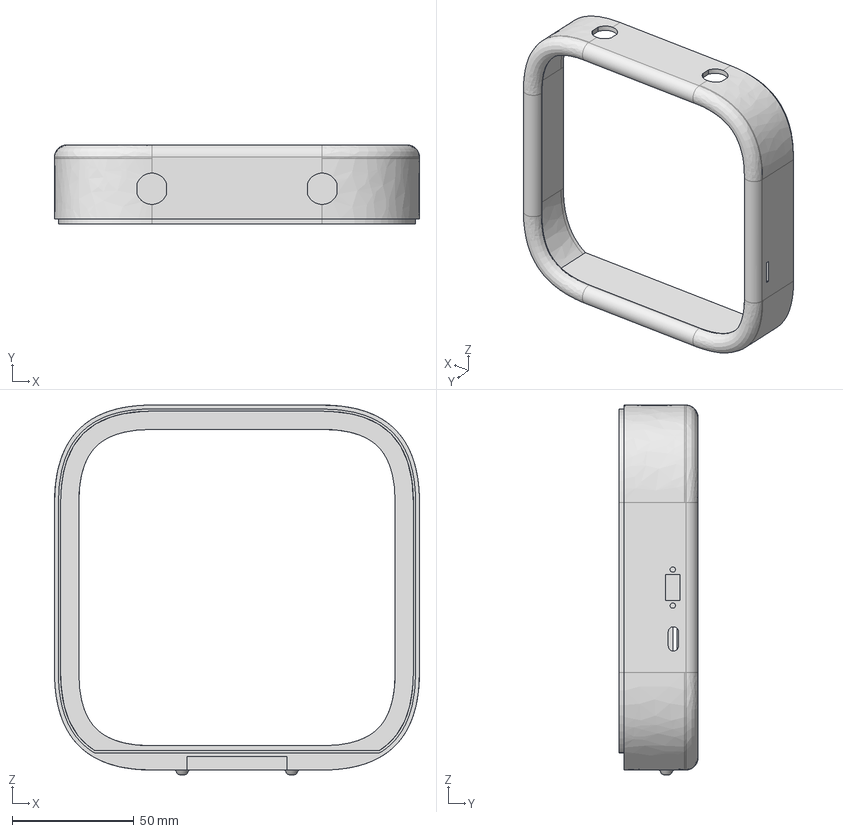
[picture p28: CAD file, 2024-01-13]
enclosure/back-bezel.step
150.0 x 32.5 x 152.0 mm

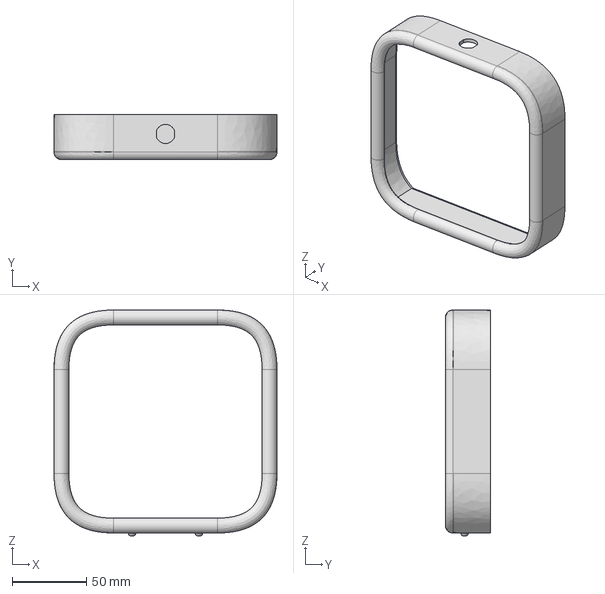
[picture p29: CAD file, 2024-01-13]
enclosure/front-bezel.step
150.0 x 30.5 x 152.0 mm

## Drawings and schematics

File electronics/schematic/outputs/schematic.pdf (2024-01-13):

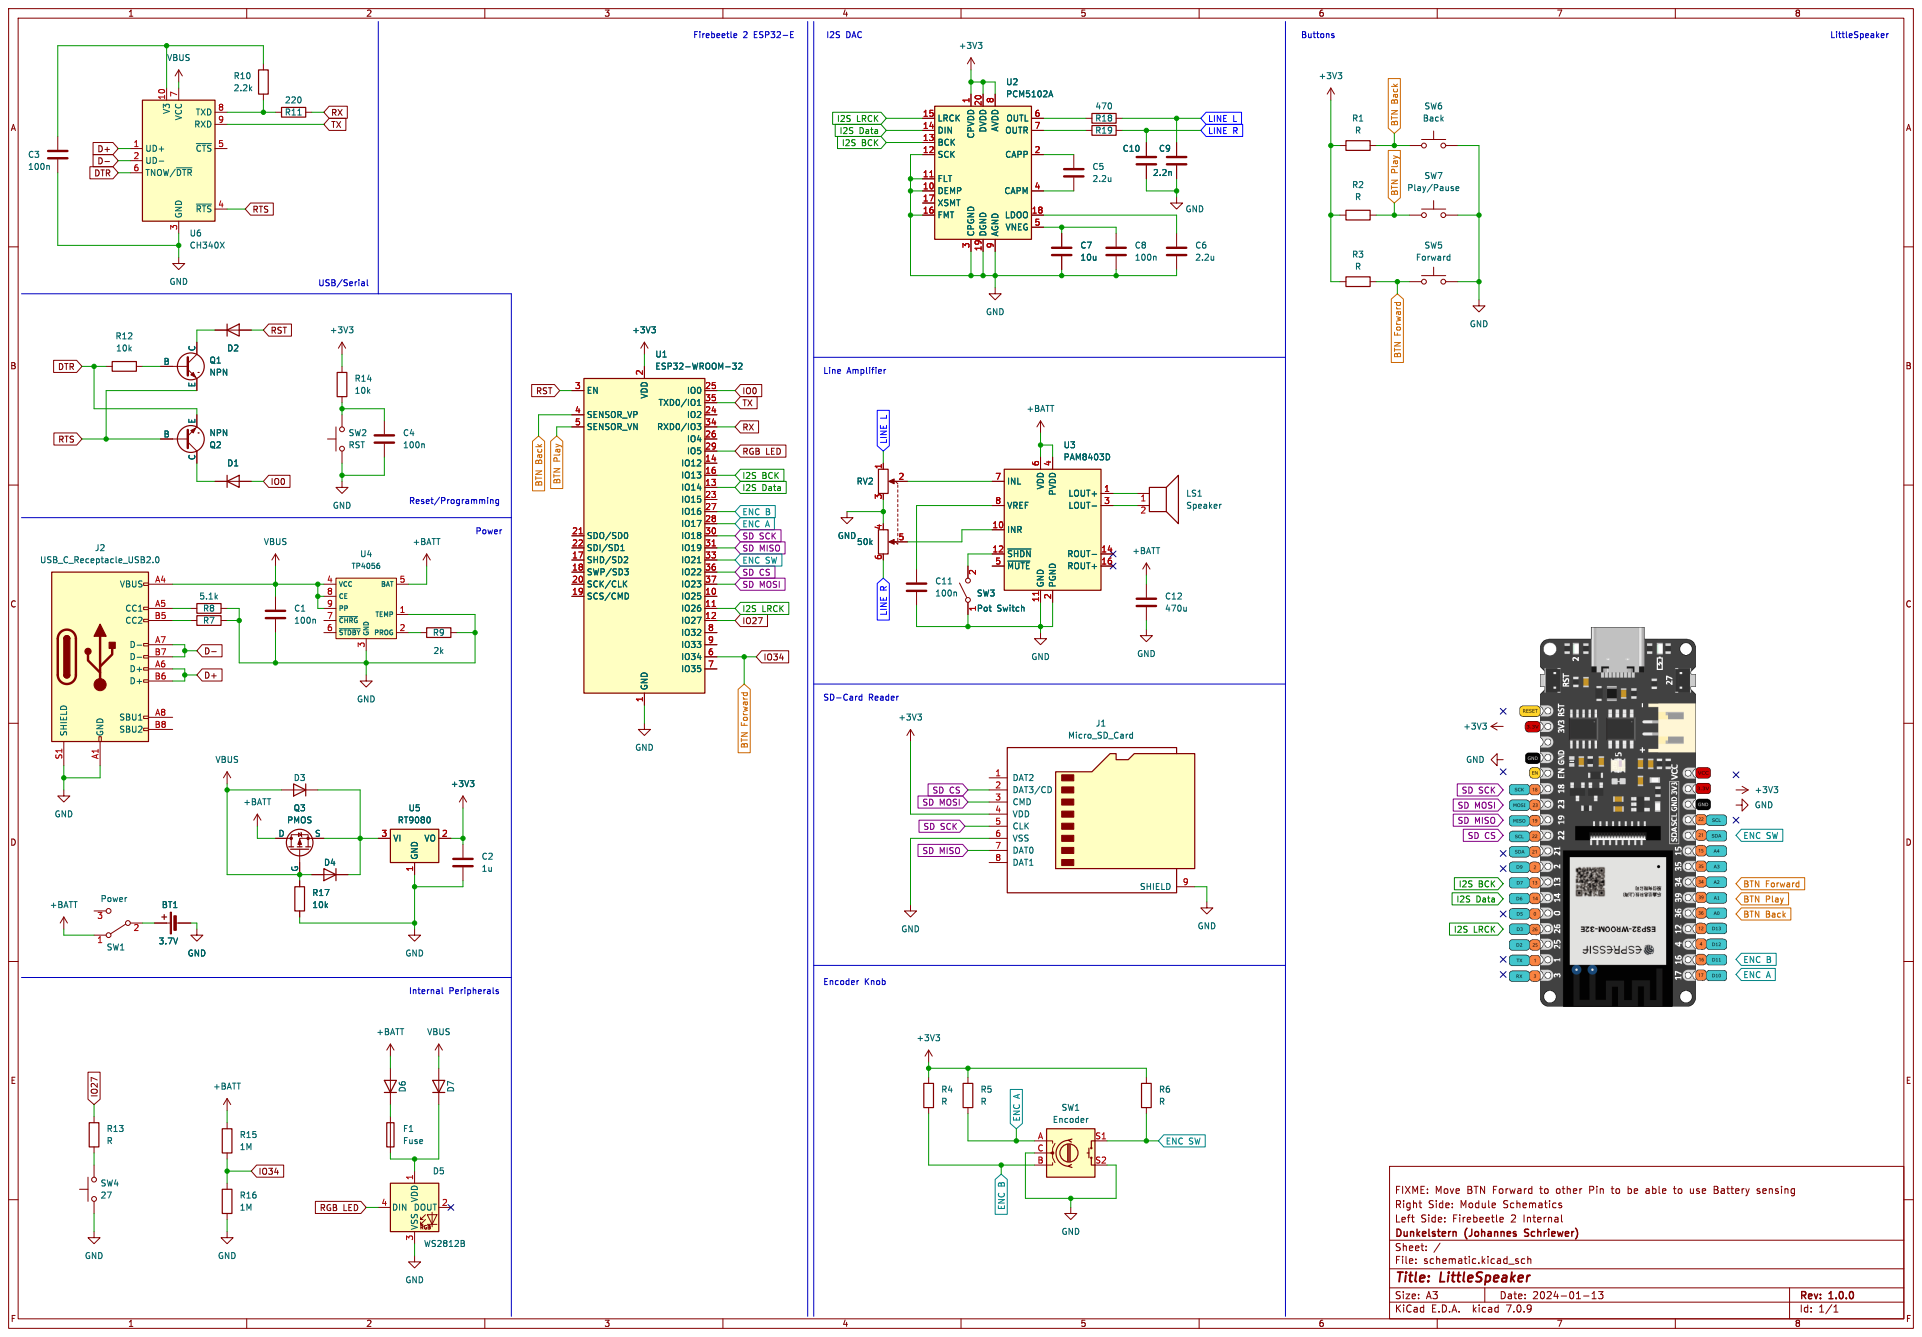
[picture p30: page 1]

1 DEMP 10 FLT 11 SCK 12 BCK 13 DIN 14

3 ~{RTS}4 ~{CTS}5 TNOW/~{DTR} 6 VCC

3 CAPM 4 VNEG 5 OUTL 6 OUTR 7 AVDD

2 SCK/CLK 20 SDO/SD0 21 SDI/SD1 22

IO27 SD SCK
SD MISO
ENC SW
SD MOSI SD CS

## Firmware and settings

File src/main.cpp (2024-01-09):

#include <Arduino.h>
#include <WiFi.h>

/*
 * PIN    GPIO    Function
 *
 * D3     26      I2S L/R Clock
 * D6     14      I2S Data
 * D7     13      I2S Base Clock
 * A0     36      Button Yellow with PullUp
 * A1     39      Button Black with PullUp
 * A2     34      Button Blue with PullUp
 * D10    17      Encoder A with PullUp
 * D11    16      Encoder B with PullUp
 * SDA    21      Encoder Button with PullUp
 * SCK    18      SD-Card SPI Clock
 * MOSI   23      SD-Card SPI MOSI
 * MISO   19      SD-Card SPI MISO
 * SCL    22      SD-Card Chip Select
 */

#define ENCODER_PIN1 17
#define ENCODER_PIN2 16

#define ENCODER_BTN 21
#define YELLOW_BTN 36
#define BLACK_BTN 39
#define BLUE_BTN 34

//
// AUDIO
//
#include "AudioOutputI2S.h"
// You may need a fast SD card. Set this as high as it will work (40MHz max).
#define SPI_SPEED 4000000u
AudioOutputI2S *output = NULL;

#include "AudioOutputFilter3BandEQ.h"
AudioOutputFilter3BandEQ *eq = NULL;

// 
// ENCODER
//
#include "RotaryEncoder.h"

RotaryEncoder encoder(ENCODER_PIN1, ENCODER_PIN2, RotaryEncoder::LatchMode::FOUR3);

//
// BUTTONS
//
#include <AceButton.h>
using namespace ace_button;

AceButton encoderButton(ENCODER_BTN);
AceButton yellowButton(YELLOW_BTN);
AceButton blackButton(BLACK_BTN);
AceButton blueButton(BLUE_BTN);

static void handleEvent(AceButton*, uint8_t, uint8_t);

//
// MENU
//
#include "menu.h"

static void debugMenu(const char *text);
static void announceMenu(const char *filename);

Menu *mainMenu = NULL;

//
// AUDIO PLAYBACK
//
#include "playlist.h"

Playlist *playlist = NULL;

//
// BLUETOOTH
//
#include "bluetooth.h"

BluetoothPlayer *btPlayer;

//
// WEBRADIO
//
#include "webradio.h"

WebradioPlayer *webPlayer;

//
// SDCARD
//
#include "sdcard.h"

SDPlayer *sdPlayer;


#include "esp_heap_caps.h"
void heap_caps_alloc_failed_hook(size_t requested_size, uint32_t caps, const char *function_name) {
  printf("%s called, failed to allocate %d bytes with 0x%X capabilities.\n", function_name, requested_size, caps);
  printf("heap free: %d, max block: %d\n", 
    heap_caps_get_free_size(caps),
    heap_caps_get_largest_free_block(caps)
  );
}


void setup() {
  // Serial
  Serial.begin(115200);
  Serial.println();
  esp_err_t error = heap_caps_register_failed_alloc_callback(heap_caps_alloc_failed_hook);
  delay(2000);

  // Turn off everything
  btStop();
  WiFi.mode(WIFI_MODE_NULL);

  // Buttons, etc.
  encoder.setPosition(0);
  
  pinMode(ENCODER_BTN, INPUT);
  pinMode(YELLOW_BTN, INPUT);
  pinMode(BLACK_BTN, INPUT);
  pinMode(BLUE_BTN, INPUT);

  ButtonConfig* buttonConfig = ButtonConfig::getSystemButtonConfig();
  buttonConfig->setEventHandler(handleEvent);
  buttonConfig->setFeature(ButtonConfig::kFeatureClick);
  buttonConfig->setClickDelay(500);
  buttonConfig->setLongPressDelay(1000);

  // SD-Card access
  if (!SD.begin(22, SPI, SPI_SPEED, "/sd", 5, false)) {
    Serial.println("SD Card could not be initialized!");
  }

  // Audio Stuff
  audioLogger = &Serial;  

  output = new AudioOutputI2S(0, AudioOutputI2S::EXTERNAL_I2S, 10, AudioOutputI2S::APLL_ENABLE);
  output->SetPinout(13, 26, 14);
  output->SetGain(0.33);

  eq = new AudioOutputFilter3BandEQ(output, 500, 5000);
  eq->setBandGains(1.5, 0.9, 1.3);

  // Audio player
  playlist = new Playlist(eq, 5);
  btPlayer = new BluetoothPlayer(playlist, eq);
  webPlayer = new WebradioPlayer(playlist);
  sdPlayer = new SDPlayer(playlist);

  // Menu definition

  MenuItem *mainMenuItems[] = {
    new MenuItem("sd", "/system/sd.mp3", sdPlayer->makeMenu()),
    new MenuItem("radio", "/system/webradio.mp3", webPlayer->makeMenu()),
    new MenuItem("bluetooth", "/system/bluetooth.mp3", btPlayer->makeMenu()),
    NULL
  };
  mainMenu = new Menu(mainMenuItems);
  mainMenu->setDisplayUpdateCallback(debugMenu);
  mainMenu->setAudioAnnounceCallback(announceMenu);

  playlist->addFilename("/system/hello.mp3");
  playlist->addFilename("/system/sd.mp3");
  playlist->play();
}


// Basically Input handling
void loop() {
  encoder.tick();
  encoderButton.check();
  yellowButton.check();
  blackButton.check();
  blueButton.check();
 
  if (encoder.getPosition() != 0) {
    if (encoder.getPosition() < 0) {
      mainMenu->selectPreviousItem();
    } else {
      mainMenu->selectNextItem();
    }
    encoder.setPosition(0);
  }

  playlist->loop();
}


//
// Menu UI
//

static void debugMenu(const char *text) {
    Serial.printf_P(PSTR("Menu item '%s' selected...\n"), text);
}

static void announceMenu(const char *filename) {
    playlist->stopAndClear();
    playlist->addFilename(filename);
    playlist->play();
}

static void handleEvent(AceButton* button, uint8_t eventType, uint8_t buttonState) {
  switch (eventType) {
    case AceButton::kEventClicked:
      if (button->getPin() == ENCODER_BTN) {
        Serial.println("Encoder button pressed");
        mainMenu->leaveItem();
      }

      if (button->getPin() == YELLOW_BTN) {
        Serial.println("Yellow button pressed");
        mainMenu->selectPreviousItem();
      }

      if (button->getPin() == BLACK_BTN) {
        Serial.println("Black button pressed");
        mainMenu->enterItem();
      }

      if (button->getPin() == BLUE_BTN) {
        Serial.println("Blue button pressed");
        mainMenu->selectNextItem();
      }
      break;
  }
}

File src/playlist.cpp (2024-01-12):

#include "driver/i2s.h"
#include "playlist.h"
#include <SD.h>

#include "AudioFileSourceICYStream.h"
#include "AudioFileSourceBuffer.h"
#include "AudioFileSourceID3.h"
#include "AudioFileSourceSD.h"
#include "AudioGeneratorMP3a.h"

const int maxFilenameLength = 256;
const int preallocateBufferSize = 6*1024;

static void metadataCallback(void *cbData, const char *type, bool isUnicode, const char *string);
static void statusCallback(void *cbData, int code, const char *string);

//
// Playlist implementation
//

Playlist::Playlist(AudioOutput *output, int maxEntries) {
    this->output = output;
    this->ringbufferSize = maxEntries;
    this->itemRingbuffer = (char **)malloc(sizeof(char *) * maxEntries);
    for(int i = 0; i < this->ringbufferSize; i++) {
        this->itemRingbuffer[i] = (char *)malloc(sizeof(char) * (maxFilenameLength + 1));
    }
    this->ringBufferMutex = xSemaphoreCreateBinary();
    xSemaphoreGive(this->ringBufferMutex);

    this->readMarker = -1;
    this->writeMarker = 0;
    this->state = PlaybackStateStopped;

    this->preallocateBuffer = NULL;
    this->base = NULL;
    this->source = NULL;
    this->decoder = NULL;
    this->endCallback = NULL;
    this->endContext = NULL;
}

Playlist::~Playlist() {
    for(int i = 0; i < this->ringbufferSize; i++) {
        free(this->itemRingbuffer[i]);
    }
    free(this->itemRingbuffer);
    if (this->preallocateBuffer) {
        free(this->preallocateBuffer);
    }
}

void Playlist::freeAllBuffers() {
    if (this->preallocateBuffer) {
        free(this->preallocateBuffer);
        this->preallocateBuffer = NULL;
    }
}

bool Playlist::addFilename(const char *filename) {
    if (strlen(filename) > maxFilenameLength) {
        // Name too long
        Serial.println("Filename too long");
        return false;
    }

    if (xSemaphoreTake(this->ringBufferMutex, 20) == pdFALSE) {
        // Could not acquire mutex
        Serial.println("Could not acquire mutex");
        return false;
    }

    if (this->writeMarker == this->readMarker - 1) {
        // Buffer full
        Serial.println("Buffer full");
        xSemaphoreGive(this->ringBufferMutex);
        return false;
    }
    
    strcpy(this->itemRingbuffer[writeMarker], filename);
    writeMarker++;
    if (writeMarker >= this->ringbufferSize) {
        writeMarker = 0;
    }

    // Buffer has an entry, set read marker to start of buffer
    if (readMarker < 0) {
        readMarker = 0;
    }

    xSemaphoreGive(this->ringBufferMutex);
    return true;
}

char* Playlist::consumeItem() {
    if (xSemaphoreTake(this->ringBufferMutex, 20) == pdFALSE) {
        // Could not acquire mutex
        return NULL;
    }

    if (this->readMarker == this->writeMarker) {
        // Buffer empty
        xSemaphoreGive(this->ringBufferMutex);
        return NULL;
    }

    char *item = NULL;
    if (this->readMarker >= 0) {
        item = this->itemRingbuffer[this->readMarker];
        this->readMarker++;
        if (this->readMarker >= this->ringbufferSize) {
            this->readMarker = 0;
        }
    } else {
        xSemaphoreGive(this->ringBufferMutex);
        return NULL;
    }
    xSemaphoreGive(this->ringBufferMutex);

    Serial.printf_P(PSTR("Consume '%s'\n"), item);
    return item;
}

PlaybackState Playlist::getState() {
    return this->state;
}

void Playlist::play() {
    if (this->state == PlaybackStateReset) {
        // wait for reset to finish
        Serial.println("Waiting for reset...");
        return;
    }
    if (this->state == PlaybackStateSkipping) {
        Serial.println("Switching from skipping to playing...");
        this->state = PlaybackStatePlaying;
        return;
    }
    if (this->state == PlaybackStatePlaying) {
        Serial.println("Already playing...");
        return;
    }

    Serial.println("Play...");
    this->state = PlaybackStatePlaying;
}

void Playlist::pause() {
    if (this->state == PlaybackStatePlaying) {
        Serial.println("Pausing...");
        this->state = PlaybackStatePaused;
        return;
    }
    if (this->state == PlaybackStatePaused) {
        Serial.println("Restarting Playback...");
        this->state = PlaybackStatePlaying;
        return;
    }
}

void Playlist::skip() {
    Serial.println("Skip");
    if ((this->state == PlaybackStatePlaying) || (this->state = PlaybackStatePaused)) {
        this->state = PlaybackStateSkipping;
    }
}

void Playlist::stopAndClear() {
    Serial.println("Stop and Clear");
    if (xSemaphoreTake(this->ringBufferMutex, 20) == pdFALSE) {
        // Could not acquire mutex
        return;
    }

    this->readMarker = -1;
    this->writeMarker = 0;
    this->state = PlaybackStateReset;
    this->endCallback = NULL;
    this->endContext = NULL;

    xSemaphoreGive(this->ringBufferMutex);
    vTaskDelay(100);
}

void Playlist::registerPlaylistEndCallback(void (*callback)(void *), void *context, bool autoClear) {
    this->endCallback = callback;
    this->endContext = context;
    this->autoClearEndContext = autoClear;
}


bool Playlist::setupAudioSourceForFile(const char *filename) {
    if (strncmp("http://", filename, 7) == 0) {
        // Webradio station
        if (!this->preallocateBuffer) {
            this->preallocateBuffer = reinterpret_cast<char *>(malloc(preallocateBufferSize));
        }
        this->base = new AudioFileSourceICYStream(filename);
        this->base->RegisterMetadataCB(metadataCallback, NULL);
        if (this->base == NULL) return false;
        this->source = new AudioFileSourceBuffer(this->base, this->preallocateBuffer, preallocateBufferSize);
        this->source->RegisterStatusCB(statusCallback, NULL);
        if (this->source == NULL) {
            this->base->close();
            delete this->base;
            this->base = NULL;
            return false;
        }
        return true;
    }
    if (strcasecmp(".mp3", filename + strlen(filename) - 4) == 0) {
        // MP3 file, get an ID3 source
        if (this->preallocateBuffer) {
            free(this->preallocateBuffer);
            this->preallocateBuffer = NULL;
        }
        this->base = new AudioFileSourceSD(filename);
        if (this->base == NULL) return false;
        this->source = new AudioFileSourceID3(this->base);
        if (this->source == NULL) {
            this->base->close();
            delete this->base;
            this->base = NULL;
            return false;
        }
        this->source->RegisterMetadataCB(metadataCallback, (void*)"ID3TAG");

        Serial.printf_P(PSTR("File '%s' is MP3, source created\n"), filename);
        return true;
    }
    return false;
}
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

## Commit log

2024-01-04 Glue everything together
2024-01-04 Fix menu context for callbacks and Constructors
    [menu.cpp]
2024-01-07 Sorry too much to track, rework the complete application
    [main.cpp, menu.cpp, playlist.cpp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]
2024-01-08 SD player UX changes
    - Do not announce track numbers in continous playback
    - Do not loop to beginning in album playback mode
    - Announce 'stopped' at end
2024-01-08 On playback stop do not reset end callback after calling it, so a new track can be appended and have a callback too
    [playlist.cpp]
2024-01-08 UX: Add connection failed message to webradio player
    [webradio.cpp]
2024-01-09 Reset i2s driver if needed
    [playlist.cpp]
2024-01-09 Bugfix: stray stop and clear
    [sdcard.cpp]
2024-01-12 Bugfix: Only stop and clear if neccessary
    [sdcard.cpp]
2024-01-12 Bugfix: Crash because of wrong auto clear callback
    [playlist.cpp]
2024-01-13 Add all the documentation and STEP files for the enclosure
    [back-bezel.step, backplate.step, front-bezel.step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]
2024-01-13 Ignore some things in the kicad folder
2024-03-13 Update enclosure images to work on dark mode
